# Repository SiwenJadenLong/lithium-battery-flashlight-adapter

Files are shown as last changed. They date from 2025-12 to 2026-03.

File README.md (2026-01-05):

# lithium-battery-flashlight-adapter
Design that uses a custom pcb and 3D printing for converting a powerful surge brand flashlight powered by 6 AA batteries for 9v to a rechargable 26650 with usb-c charging.

Why?:
I don't like AA batteries :P
and I need a bright flashflight when I'm skating home at night

Original Flashlight  page:
https://www.tractorsupply.com/tsc/product/surge-1-000-lumen-tactical-led-alkaline-flashlight-hhl3060as 

26650 Battery in interest:
https://www.18650batterystore.com/products/sinowatt-70hp-26650-7000mah-14a-battery

Digikey parts list:
https://www.digikey.com/en/mylists/list/EGW4OOC67G

# Plan:
1.  (WE ARE HERE) Create a circular pcb that boosts battery voltage to 9v and allows for usb-c recharging, does not have to do both at the same time. 
2. Create 3D printing casing for adapter
3. assemble
4. profit?

PCB V1:
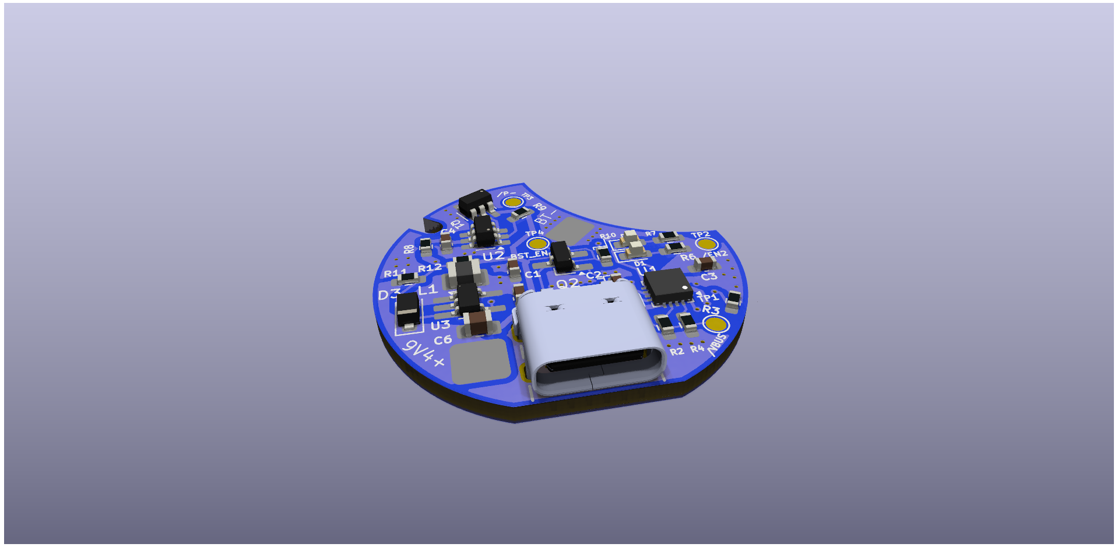
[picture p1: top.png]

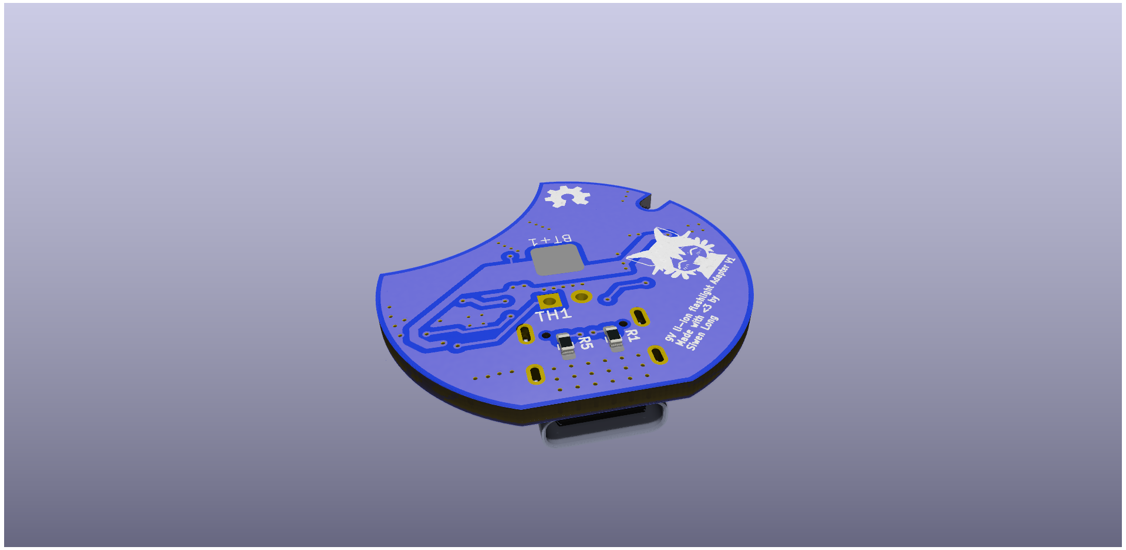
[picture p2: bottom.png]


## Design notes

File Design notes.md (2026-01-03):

---
# yaml-language-server: $schema=schemas\page.schema.json
Object type:
    - Page
Creation date: "2025-12-29T03:11:33Z"
Created by:
    - Siwen Long
Links:
    - Samsung 58E (CC5493F101) 5330mAh 10.7A Battery
    - Sinowatt 70HP 26650 7000mAh 14A Battery
id: bafyreic3wo3inzjztajtzenbvojdvyxrgd2omhgpq4noxvgmcx3pduz5ye
---
# Giant Flashlight Adapter   
Output 9v   
Average amperage draw, as measured with my multimeter, 320mA, it dropped from about 500mA over the course of 30secs.   
   
space expressed as cylinder:   
-104mm high   
-30.7mm dia   
   
Stated manufacturer specs:   
with 6 AA batteries in series for 9v,   
battery life of 2hrs.   
~~Assuming 2AH, that seems like an average draw of 1A~~ 1/3/26 way off compared to measurements   
   
[https://www.tractorsupply.com/tsc/product/surge-1-000-lumen-tactical-led-alkaline-flashlight-hhl3060as](https://www.tractorsupply.com/tsc/product/surge-1-000-lumen-tactical-led-alkaline-flashlight-hhl3060as)    
   
21700 Battery in interest:   
[Samsung 58E (CC5493F101) 5330mAh 10.7A Battery](https://www.18650batterystore.com/products/samsung-inr21700-58e-cc5493f101-5330mah-10-7a)    
26650 Battery in interest:   
[Sinowatt 70HP 26650 7000mAh 14A Battery](https://www.18650batterystore.com/products/sinowatt-70hp-26650-7000mah-14a-battery)    
Available components:   
- 3 gold plated Spring contacts   

PCB constrants:   
- Diameter of no more than 30mm   
- 2 Layer board   
- USB-C port needs to stick out enough for charging   

ICs of choice:   
- Battery charging: BQ2407   
    - Choose this because of low cost, low package complexity, 1.5A charging current   
- Battery protection: DW01A   
    - For preventing over discharging from the buck   
    - needs 2 N-Channel depletion mosfets   
- Voltage boast: MIC2295   
    - 1.2 Amp max, 74% efficiency at 1.2A, flashlight should pull about 1A. I'll need to test    

Battery life calculations:   
Battery: 7000mAh \| 4.2V   
Need to output: 9V 320mA/500mA (estimate/conservative)   
Efficiency of 74%   
   
Brain spill:   
- From negative terminal, I can run a wire to the pcb for ground   
- PCB can have spring terminal on bottom for space saving or I can run a wire   
- Haven't figured out how to maintain pressure to keep the springs touching. Thinking I can use the screws pressing of the end caps somehow, may be complicated. Oh wait →   
- I can have the negative cap need to be removed to insert the battery and then press the bottom cap against the battery using the screws that will go to the 3D printed housing   
- Will need a small donut hole in the pcb for wire of the positive end of the battery to the pcb.    
- Or I can coil up the wire and solder it only to the bottom of the pcb for more space. This would eliminate the potential issues of space on the pcb and I think I'd have the vertical space for it   
- Need to modify pcb, put holes in it for when I need to sandwich the plastic piece on top, not sure how to connect the 3D prints after I sandwich the pcb.

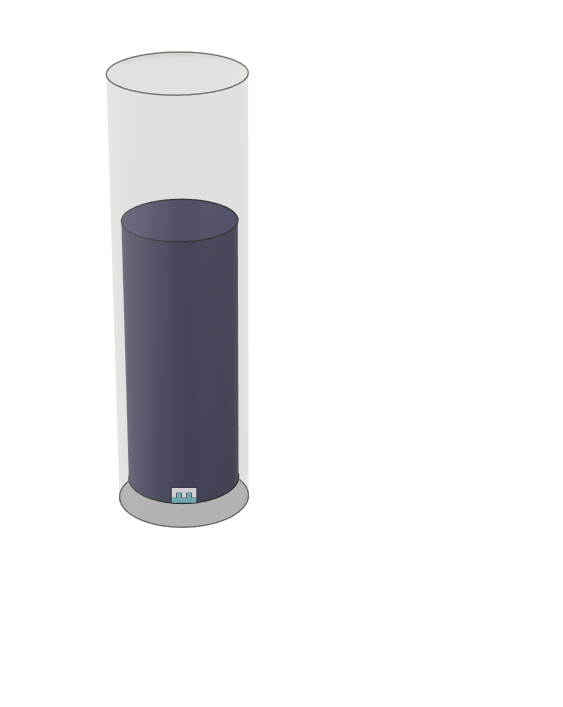
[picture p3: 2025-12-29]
prelim_cad.png

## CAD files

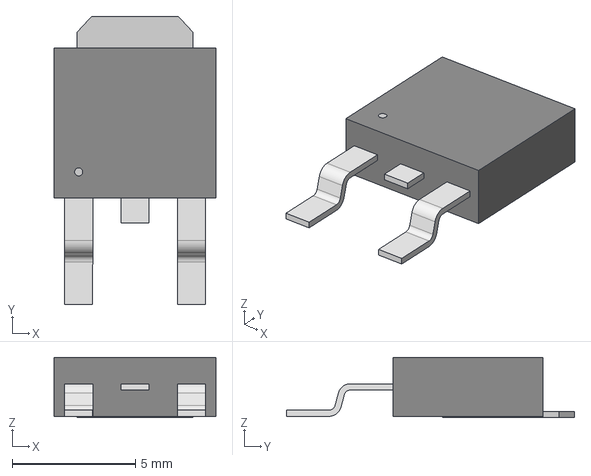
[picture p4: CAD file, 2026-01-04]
PCB/flashlight adapter/Downloaded/DN2625K4_G/TO-252-3_MCH.step
6.55 x 11.7 x 2.44 mm

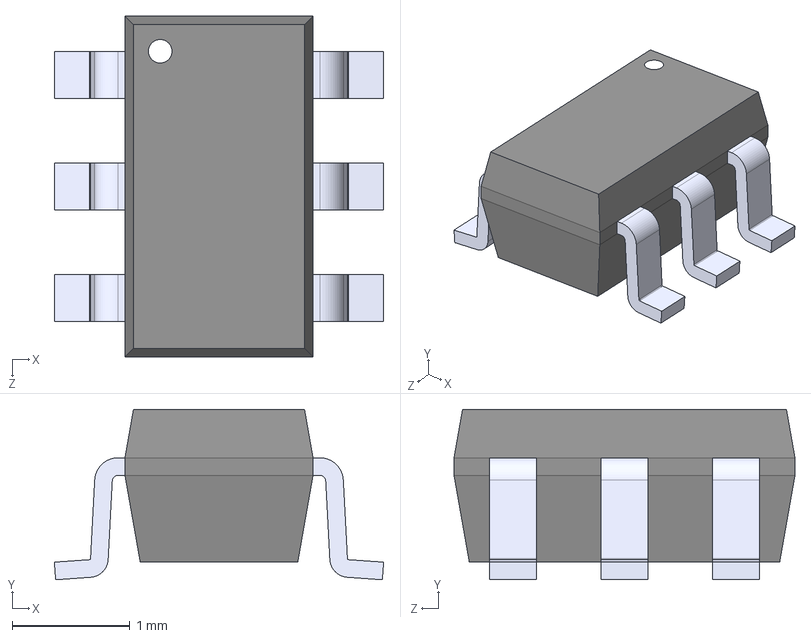
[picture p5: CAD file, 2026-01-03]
PCB/flashlight adapter/Downloaded/DW01A/DW01A.step
2.80 x 1.45 x 2.90 mm

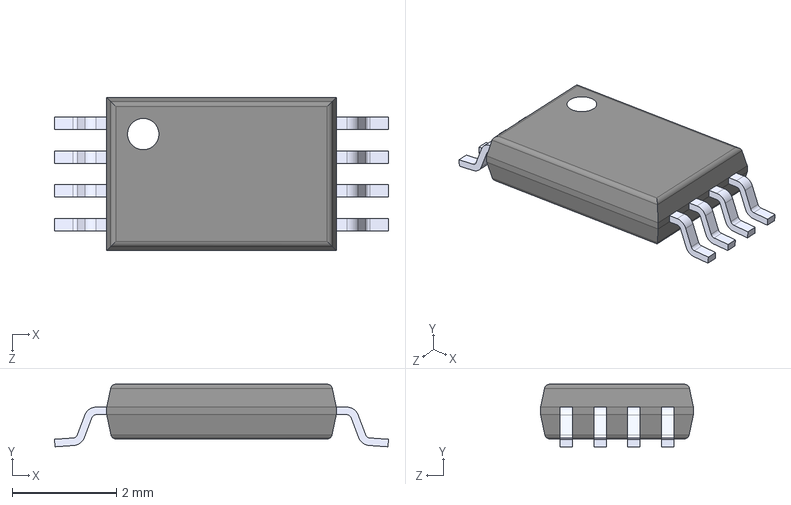
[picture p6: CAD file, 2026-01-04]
PCB/flashlight adapter/Downloaded/FS8205A/FS8205A.step
6.40 x 1.20 x 2.93 mm

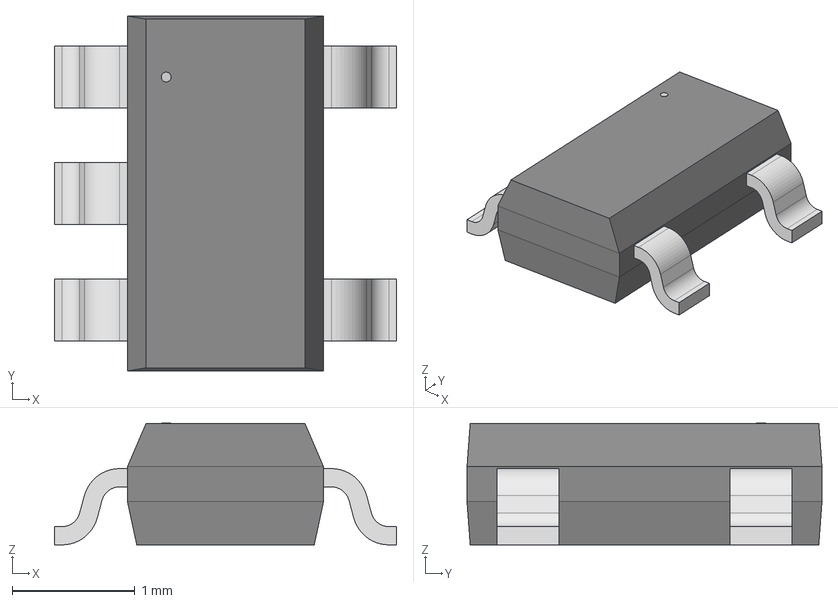
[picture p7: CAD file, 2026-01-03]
PCB/flashlight adapter/Downloaded/MIC2295YD5_TR/TSOT-23-5_D5_MCH.step
2.79 x 2.90 x 0.993 mm

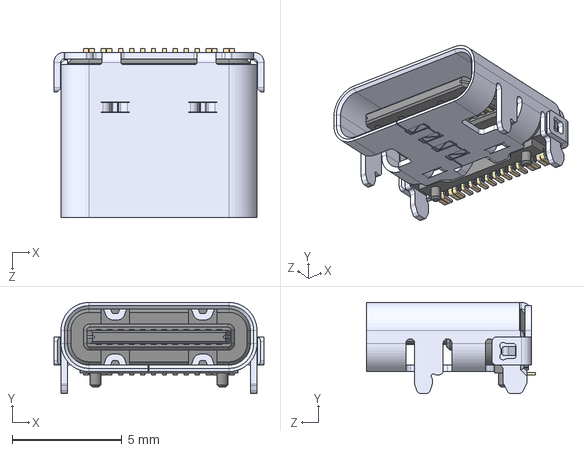
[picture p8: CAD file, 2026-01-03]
PCB/flashlight adapter/Downloaded/USB4105_GF_A/USB4105-GF-A.step
9.58 x 4.16 x 7.71 mm

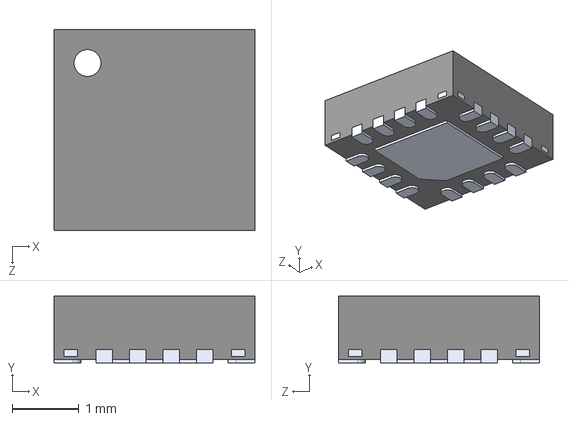
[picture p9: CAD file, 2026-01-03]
PCB/flashlight adapter/Downloaded/BQ24074RGTR/BQ24074RGTR.step
3.00 x 1.00 x 3.00 mm

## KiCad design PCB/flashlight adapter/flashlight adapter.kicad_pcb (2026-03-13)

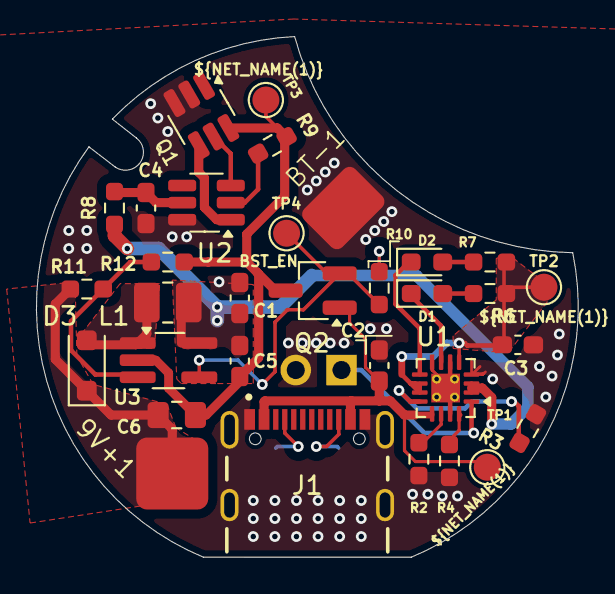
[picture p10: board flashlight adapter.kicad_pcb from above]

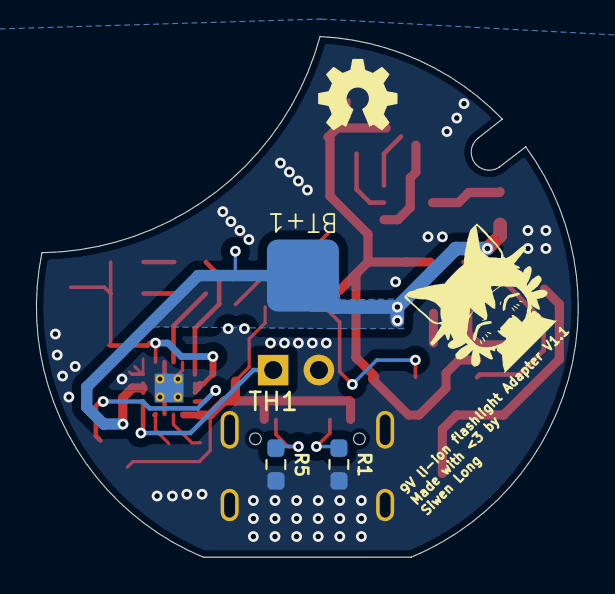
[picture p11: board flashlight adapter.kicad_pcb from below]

Board: 2 copper layers, 30.1 x 28.9 mm, 36 parts (4 on the bottom side), 23 nets.

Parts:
9V+1: 9V; 4mm_by_4mm_pad
BT+1: BATT+; 4mm_by_4mm_pad
BT-1: BATT-; 3mm_by_4mm_pad
C1, C3, C5: 4.7 uF; C_0603_1608Metric_Pad1.08x0.95mm_HandSolder
C2: 1uF; C_0603_1608Metric_Pad1.08x0.95mm_HandSolder
C4: 0.1uF; C_0603_1608Metric_Pad1.08x0.95mm_HandSolder
C6: 10uF; C_0805_2012Metric_Pad1.18x1.45mm_HandSolder
D1: RED; LED_0603_1608Metric_Pad1.05x0.95mm_HandSolder
D2: GREEN; LED_0603_1608Metric_Pad1.05x0.95mm_HandSolder
D3: D_Schottky; D_SOD-123F
J1: USB4105-GF-A; GCT_USB4105-GF-A
L1: 4.7uH; L_1008_2520Metric_Pad1.43x2.20mm_HandSolder
Q1: FS8205A; SOT-23-6_Handsoldering
Q2: Q_NMOS_GSD; SOT-23_Handsoldering
R1, R5, R10: 10k; R_0603_1608Metric_Pad0.98x0.95mm_HandSolder
R2: 51k; R_0603_1608Metric_Pad0.98x0.95mm_HandSolder
R3: 1.1kΩ; R_0603_1608Metric_Pad0.98x0.95mm_HandSolder
R4: 590Ω; R_0603_1608Metric_Pad0.98x0.95mm_HandSolder
R6, R7: 120Ω; R_0603_1608Metric_Pad0.98x0.95mm_HandSolder
R8: 470Ω; R_0603_1608Metric_Pad0.98x0.95mm_HandSolder
R9: 2kΩ; R_0603_1608Metric_Pad0.98x0.95mm_HandSolder
R11: 28k; R_0603_1608Metric_Pad0.98x0.95mm_HandSolder
R12: 4.3k; R_0603_1608Metric_Pad0.98x0.95mm_HandSolder
TH1: 10K; PinHeader_1x02_P2.54mm_Vertical
TP1: VBUS; TestPoint_Pad_D1.5mm
TP2: OUT; TestPoint_Pad_D1.5mm
TP3: P+ & BATT+; TestPoint_Pad_D1.5mm
TP4: BST EN; TestPoint_Pad_D1.5mm
U1: BQ24074RGT; VQFN-16-1EP_3x3mm_P0.5mm_EP1.6x1.6mm_ThermalVias
U2: DW01A; SOT-23-6_Handsoldering
U3: MIC2295YD5-TR; TSOT-23-5_HandSoldering

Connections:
/BAT: BT+1.1, C1.1, C5.1, L1.1, R8.1, R10.1, U1.2 (BAT), U1.3 (BAT), U3.5 (VIN)
/EN2: C3.1, R6.2, R7.2, TP2.1, U1.5 (EN2), U1.10 (OUT), U1.11 (OUT)
/P-: C5.2, C6.2, Q1.6, Q2.3 (S), R9.2, R12.2, TP3.1, U3.2 (GND)
/TS: TH1.1, U1.1 (TS)
/VBUS: C2.1, J1.A4_B9 (VBUS), J1.B4_A9 (VBUS__1), Q2.1 (G), TP1.1, U1.13 (IN)
GND: BT-1.1, C1.2, C2.2, C3.2, C4.2, J1.A1_B12 (GND), J1.B1_A12 (GND__1), J1.SH1 (SHELL_GND), J1.SH2 (SHELL_GND__1), J1.SH3 (SHELL_GND__2), J1.SH4 (SHELL_GND__3), Q1.2, Q1.3, R1.2, R2.2, R3.2, R4.2, R5.2, TH1.2, U1.4 (~CE), U1.6 (EN1), U1.8 (VSS), U1.15 (ITERM), U1.17 (VSS), U2.6 (GND)
unnamed: D1.2 (A), R6.1
unnamed: D1.1 (K), U1.7 (~PGOOD)
unnamed: D2.2 (A), R7.1
unnamed: D2.1 (K), U1.9 (~CHG)
unnamed: D3.2 (A), L1.2, U3.1 (SW)
unnamed: 9V+1.1, C6.1, D3.1 (K), R11.1
unnamed: J1.A5 (CC1), R1.1
unnamed: J1.B5 (CC2), R5.1
unnamed: Q2.2 (D), R10.2, TP4.1, U3.4 (EN)
unnamed: R3.1, U1.12 (ILIM)
unnamed: R4.1, U1.16 (ISET)
unnamed: R2.1, U1.14 (TMR)
unnamed: R9.1, U2.2 (CS)
unnamed: Q1.5, U2.3 (OC)
unnamed: Q1.4, U2.1 (OD)
unnamed: C4.1, R8.2, U2.5 (VCC)
unnamed: R11.2, R12.1, U3.3 (FB)

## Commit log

2026-01-03 added flowchart, picked out components, started pcb design
    [BQ24074RGTR.step, DW01A.step, TSOT-23-5_D5_MCH.step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]
2026-01-04 Completed Charging IC schematic
    [flashlight adapter.kicad_sch]
2026-01-04 finished low voltage cutoff ic
    [flashlight adapter.kicad_sch]
2026-01-04 almost completed boast converter, waiting on inductor resistor feedback
    [flashlight adapter.kicad_sch]
2026-01-04 Pretty much finished schematic
    [TO-252-3_MCH.step, flashlight adapter.kicad_sch]
2026-01-04 Intial layout complete with DRC, test pads to be added
    [FS8205A.step, flashlight adapter.kicad_pcb, flashlight adapter.kicad_sch]
2026-01-05 Added Boost off when charging
    [flashlight adapter-B_Cu.gbr, flashlight adapter-B_Mask.gbr, flashlight adapter-B_Paste.gbr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]
2026-03-13 Fixed usb switch mosfet footprint, sent out second order
    [flashlight adapter.kicad_pcb, flashlight adapter.kicad_sch]
2026-03-13 Adjusted Silkscreen to say v1.1
    [flashlight adapter.kicad_pcb]
